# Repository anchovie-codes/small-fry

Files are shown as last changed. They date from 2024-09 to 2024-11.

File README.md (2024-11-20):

# small-fry

silkscreen-noborder
rev. 1 prototype

## parts needed

- 1x Raspberry Pi Pico (make sure you get an [authentic one](https://www.raspberrypi.com/products/raspberry-pi-pico/) with the castellated pins)
- 69x SOD123 diodes (e.g. [1N4148W](https://www.digikey.com/en/products/detail/micro-commercial-co/1N4148W-TP/717196))
- 69 MX or Alps switches (i **strongly recommend MX** unless you are confident in fabricating your own keycaps)
- 2x 2U stabilizers
- 53x 1U keycaps
- 14x 1.75U keycaps
- 1x 2.25U keycap
- 1x 2.75U keycap

## tools needed

- **a heat gun + solder paste are highly recommended** for soldering the diodes, however they can be hand-soldered if you are patient and skilled.
- soldering iron + solder  wire for soldering the switches and MCU.

## assembly notes

- diode direction is COL to ROW! this means the lines should face down (if you're using the diodes linked above).
- this PCB does not have holes for tray-mounting; it must be plate-mounted to a case.
- switchplate .DXF file is included; it should be ~1.5mm thick. recommended material is either metal or FR4. acrylic is technically viable but will add flex.

### sandwich case notes

some .DXF files are included for a rudimentary sandwich case. additional hardware needed:
- 10x M3x8mm male-to-female standoffs (M3x10 will also work, just makes the height taller)
- 10x M3x4mm screws
- 10x M3x6x5mm heat-threaded inserts

required thickness of each plate:
- top plate: 1.5-3mm
- mid plate: 3mm
- buffer plate: 3mm
- bottom plate: 1.5-3mm

stacking order of plates is, from top to bottom:
- top plate
- mid plate
- buffer plate
- switch plate
- bottom plate

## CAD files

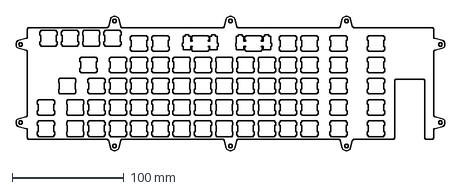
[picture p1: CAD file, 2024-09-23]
sf switch plate.dxf
383.6 x 120.0 mm

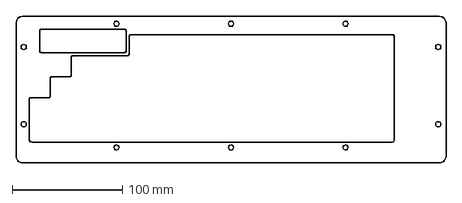
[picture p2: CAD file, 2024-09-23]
sf mid plate.dxf
389.6 x 133.0 mm

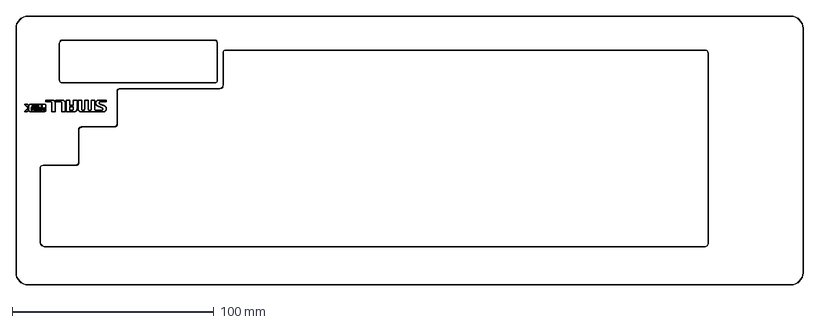
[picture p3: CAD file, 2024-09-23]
sf top plate.dxf
389.6 x 133.0 mm

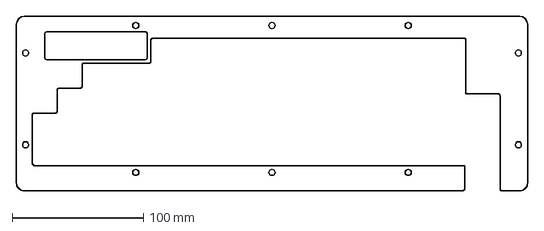
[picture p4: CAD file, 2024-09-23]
sf buffer plate.dxf
389.6 x 133.0 mm

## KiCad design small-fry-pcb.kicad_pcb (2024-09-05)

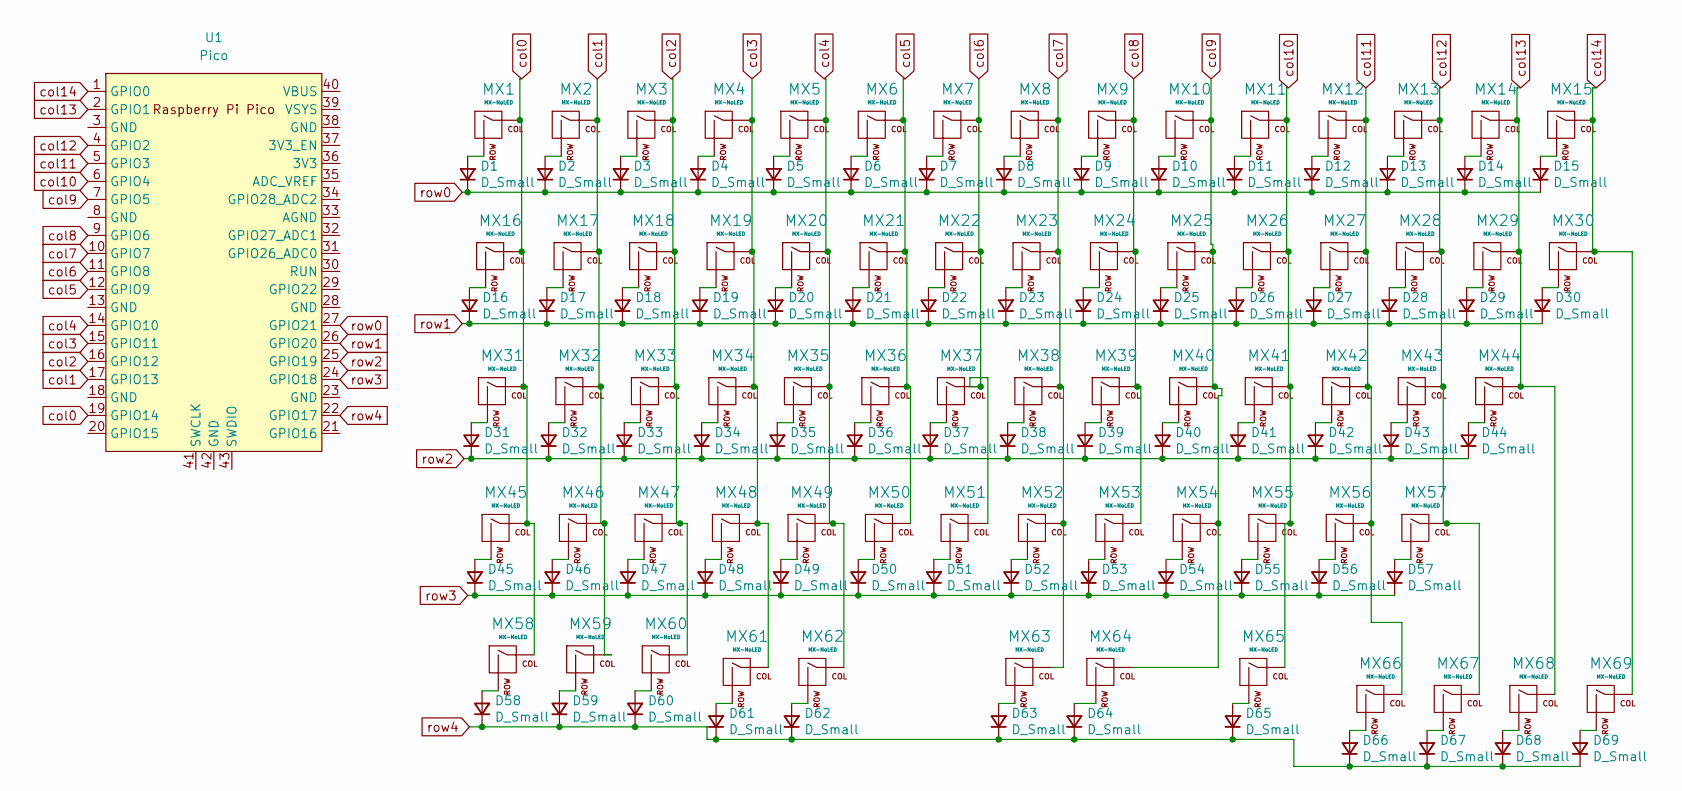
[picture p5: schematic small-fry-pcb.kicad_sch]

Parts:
D1, D2, D3, D4, D5, D6, D7, D8, D9, D10, D11, D12, D13, D14, D15, D16, D17, D18, D19, D20, D21, D22, D23, D24, D25, D26, D27, D28, D29, D30, D31, D32, D33, D34, D35, D36, D37, D38, D39, D40, D41, D42, D43, D44, D45, D46, D47, D48, D49, D50, D51, D52, D53, D54, D55, D56, D57, D58, D59, D60, D61, D62, D63, D64, D65, D66, D67, D68, D69: D_Small; D_SOD-123
MX1, MX2, MX15, MX16, MX17, MX30, MX31, MX32, MX44, MX45, MX46, MX57, MX58, MX59: MX-NoLED; MX-1.75U-NoLED
MX3, MX4, MX5, MX6, MX7, MX8, MX9, MX10, MX11, MX12, MX13, MX14, MX18, MX19, MX20, MX21, MX22, MX23, MX24, MX25, MX26, MX27, MX28, MX29, MX33, MX34, MX35, MX36, MX37, MX38, MX39, MX40, MX41, MX42, MX43, MX47, MX48, MX49, MX50, MX51, MX52, MX53, MX54, MX55, MX56, MX60, MX61, MX64, MX65, MX66, MX67, MX68, MX69: MX-NoLED; MX-1U-NoLED
MX62: MX-NoLED; MX-2.25U-ReversedStabilizers-NoLED
MX63: MX-NoLED; MX-2.75U-ReversedStabilizers-NoLED
U1: Pico; RPi_Pico_SMD_TH

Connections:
unnamed: D1.2 (A), MX1.2 (ROW)
unnamed: D2.2 (A), MX2.2 (ROW)
unnamed: D3.2 (A), MX3.2 (ROW)
unnamed: D4.2 (A), MX4.2 (ROW)
unnamed: D5.2 (A), MX5.2 (ROW)
unnamed: D6.2 (A), MX6.2 (ROW)
unnamed: D7.2 (A), MX7.2 (ROW)
unnamed: D8.2 (A), MX8.2 (ROW)
unnamed: D9.2 (A), MX9.2 (ROW)
unnamed: D10.2 (A), MX10.2 (ROW)
unnamed: D11.2 (A), MX11.2 (ROW)
unnamed: D12.2 (A), MX12.2 (ROW)
unnamed: D13.2 (A), MX13.2 (ROW)
unnamed: D14.2 (A), MX14.2 (ROW)
unnamed: D15.2 (A), MX15.2 (ROW)
unnamed: D16.2 (A), MX16.2 (ROW)
unnamed: D17.2 (A), MX17.2 (ROW)
unnamed: D18.2 (A), MX18.2 (ROW)
unnamed: D19.2 (A), MX19.2 (ROW)
unnamed: D20.2 (A), MX20.2 (ROW)
unnamed: D21.2 (A), MX21.2 (ROW)
unnamed: D22.2 (A), MX22.2 (ROW)
unnamed: D23.2 (A), MX23.2 (ROW)
unnamed: D24.2 (A), MX24.2 (ROW)
unnamed: D25.2 (A), MX25.2 (ROW)
unnamed: D26.2 (A), MX26.2 (ROW)
unnamed: D27.2 (A), MX27.2 (ROW)
unnamed: D28.2 (A), MX28.2 (ROW)
unnamed: D29.2 (A), MX29.2 (ROW)
unnamed: D30.2 (A), MX30.2 (ROW)
unnamed: D31.2 (A), MX31.2 (ROW)
unnamed: D32.2 (A), MX32.2 (ROW)
unnamed: D33.2 (A), MX33.2 (ROW)
unnamed: D34.2 (A), MX34.2 (ROW)
unnamed: D35.2 (A), MX35.2 (ROW)
unnamed: D36.2 (A), MX36.2 (ROW)
unnamed: D37.2 (A), MX37.2 (ROW)
unnamed: D38.2 (A), MX38.2 (ROW)
unnamed: D39.2 (A), MX39.2 (ROW)
unnamed: D40.2 (A), MX40.2 (ROW)
unnamed: D41.2 (A), MX41.2 (ROW)
unnamed: D42.2 (A), MX42.2 (ROW)
unnamed: D43.2 (A), MX43.2 (ROW)
unnamed: D44.2 (A), MX44.2 (ROW)
unnamed: D45.2 (A), MX45.2 (ROW)
unnamed: D46.2 (A), MX46.2 (ROW)
unnamed: D47.2 (A), MX47.2 (ROW)
unnamed: D48.2 (A), MX48.2 (ROW)
unnamed: D49.2 (A), MX49.2 (ROW)
unnamed: D50.2 (A), MX50.2 (ROW)
unnamed: D51.2 (A), MX51.2 (ROW)
unnamed: D52.2 (A), MX52.2 (ROW)
unnamed: D53.2 (A), MX53.2 (ROW)
unnamed: D54.2 (A), MX54.2 (ROW)
unnamed: D55.2 (A), MX55.2 (ROW)
unnamed: D56.2 (A), MX56.2 (ROW)
unnamed: D57.2 (A), MX57.2 (ROW)
unnamed: D58.2 (A), MX58.2 (ROW)
unnamed: D59.2 (A), MX59.2 (ROW)
unnamed: D60.2 (A), MX60.2 (ROW)
unnamed: D61.2 (A), MX61.2 (ROW)
unnamed: D62.2 (A), MX62.2 (ROW)
unnamed: D63.2 (A), MX63.2 (ROW)
unnamed: D64.2 (A), MX64.2 (ROW)
unnamed: D65.2 (A), MX65.2 (ROW)
unnamed: D66.2 (A), MX66.2 (ROW)
unnamed: D67.2 (A), MX67.2 (ROW)
unnamed: D68.2 (A), MX68.2 (ROW)
unnamed: D69.2 (A), MX69.2 (ROW)
col0: MX1.1 (COL), MX16.1 (COL), MX31.1 (COL), MX45.1 (COL), MX58.1 (COL), U1.19 (GPIO14)
col1: MX2.1 (COL), MX17.1 (COL), MX32.1 (COL), MX46.1 (COL), MX59.1 (COL), U1.17 (GPIO13)
col2: MX3.1 (COL), MX18.1 (COL), MX33.1 (COL), MX47.1 (COL), MX60.1 (COL), U1.16 (GPIO12)
col3: MX4.1 (COL), MX19.1 (COL), MX34.1 (COL), MX48.1 (COL), MX61.1 (COL), U1.15 (GPIO11)
col4: MX5.1 (COL), MX20.1 (COL), MX35.1 (COL), MX49.1 (COL), MX62.1 (COL), U1.14 (GPIO10)
col5: MX6.1 (COL), MX21.1 (COL), MX36.1 (COL), MX50.1 (COL), U1.12 (GPIO9)
col6: MX7.1 (COL), MX22.1 (COL), MX37.1 (COL), MX51.1 (COL), U1.11 (GPIO8)
col7: MX8.1 (COL), MX23.1 (COL), MX38.1 (COL), MX52.1 (COL), MX63.1 (COL), U1.10 (GPIO7)
col8: MX9.1 (COL), MX24.1 (COL), MX39.1 (COL), MX53.1 (COL), U1.9 (GPIO6)
col9: MX10.1 (COL), MX25.1 (COL), MX40.1 (COL), MX54.1 (COL), MX64.1 (COL), U1.7 (GPIO5)
col10: MX11.1 (COL), MX26.1 (COL), MX41.1 (COL), MX55.1 (COL), MX65.1 (COL), U1.6 (GPIO4)
col11: MX12.1 (COL), MX27.1 (COL), MX42.1 (COL), MX56.1 (COL), MX66.1 (COL), U1.5 (GPIO3)
col12: MX13.1 (COL), MX28.1 (COL), MX43.1 (COL), MX57.1 (COL), MX67.1 (COL), U1.4 (GPIO2)
col13: MX14.1 (COL), MX29.1 (COL), MX44.1 (COL), MX68.1 (COL), U1.2 (GPIO1)
col14: MX15.1 (COL), MX30.1 (COL), MX69.1 (COL), U1.1 (GPIO0)
row0: D1.1 (K), D2.1 (K), D3.1 (K), D4.1 (K), D5.1 (K), D6.1 (K), D7.1 (K), D8.1 (K), D9.1 (K), D10.1 (K), D11.1 (K), D12.1 (K), D13.1 (K), D14.1 (K), D15.1 (K), U1.27 (GPIO21)
row1: D16.1 (K), D17.1 (K), D18.1 (K), D19.1 (K), D20.1 (K), D21.1 (K), D22.1 (K), D23.1 (K), D24.1 (K), D25.1 (K), D26.1 (K), D27.1 (K), D28.1 (K), D29.1 (K), D30.1 (K), U1.26 (GPIO20)
row2: D31.1 (K), D32.1 (K), D33.1 (K), D34.1 (K), D35.1 (K), D36.1 (K), D37.1 (K), D38.1 (K), D39.1 (K), D40.1 (K), D41.1 (K), D42.1 (K), D43.1 (K), D44.1 (K), U1.25 (GPIO19)
row3: D45.1 (K), D46.1 (K), D47.1 (K), D48.1 (K), D49.1 (K), D50.1 (K), D51.1 (K), D52.1 (K), D53.1 (K), D54.1 (K), D55.1 (K), D56.1 (K), D57.1 (K), U1.24 (GPIO18)
row4: D58.1 (K), D59.1 (K), D60.1 (K), D61.1 (K), D62.1 (K), D63.1 (K), D64.1 (K), D65.1 (K), D66.1 (K), D67.1 (K), D68.1 (K), D69.1 (K), U1.22 (GPIO17)

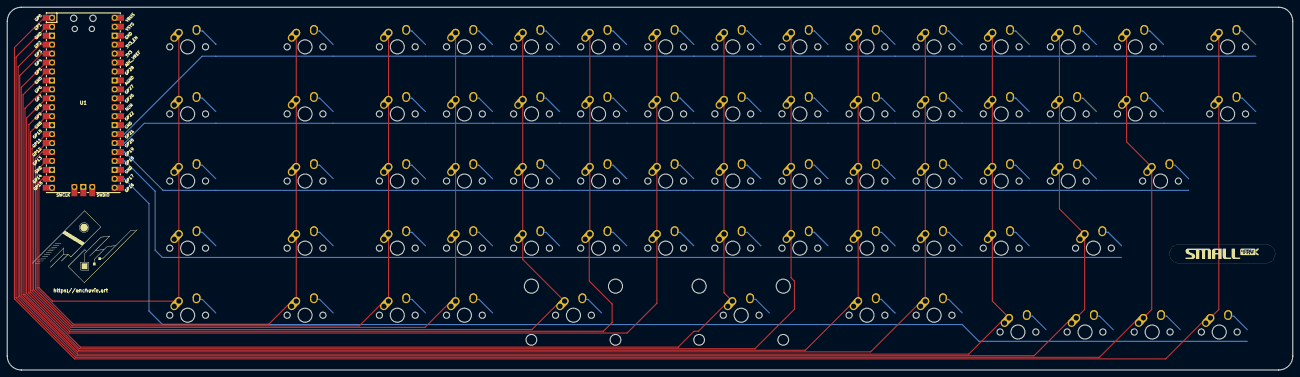
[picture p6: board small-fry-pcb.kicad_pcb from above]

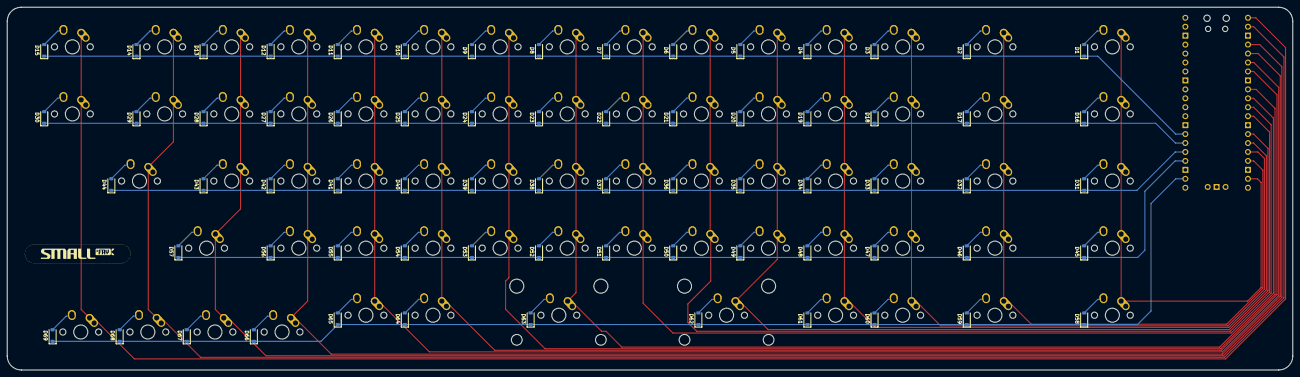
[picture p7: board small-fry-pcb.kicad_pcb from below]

Board: 2 copper layers, 365.0 x 103.0 mm, 139 parts (69 on the bottom side), 89 nets.

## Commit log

2024-08-31 added kicad files
    [small-fry-pcb.kicad_pcb, small-fry-pcb.sch]
2024-08-31 updated schematic
2024-08-31 updated schematic and fixed footprints
    [small-fry-pcb.sch]
2024-09-01 added controller footprint and symbol
    [small-fry-pcb.kicad_pcb]
2024-09-04 Squashed commit of the following:
    commit 3a31e5c864698379eab5fa9799b6646026e60a6b
    Author: anchovie-codes <littlebrother.free@gmail.com>
    Date: Mon Sep 2 00:25:19 2024 -0400
    backup file changes
    commit 27ca4d82953605882c5c8308233a3a86d2bdc34d
    Author: anchovie-codes <littlebrother.free@gmail.com>
    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
    [small-fry-pcb.kicad_pcb, small-fry-pcb.kicad_sch]
2024-09-04 Squashed commit of the following:
    commit 176f3bbe4c1d8503f8e6634e84449ff57851d2da
    Date: Wed Sep 4 12:11:39 2024 -0400
    updated backup
    commit faa0e4d37d006ebb0d8ebb4d260e99f9d3fc7be4
    Date: Wed Sep 4 12:06:31 2024 -0400
    adjusted col traces and silkscreen
    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
    [small-fry-pcb.kicad_pcb, small-fry-pcb.kicad_sch]
2024-09-05 generated gerbers
    [small-fry-pcb-B_Cu.gbl, small-fry-pcb-B_Mask.gbs, small-fry-pcb-B_Silkscreen.gbo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]
2024-09-16 pcb backup updates
